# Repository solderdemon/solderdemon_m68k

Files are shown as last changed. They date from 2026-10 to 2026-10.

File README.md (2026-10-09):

# SolderDemon m68k

Assembled rosco r2.42 mainboard, the GAL version SolderDemon m68k r1 grew from

SolderDemon develops a line of Motorola 68k computers built from **through-hole (THT) parts**. This repository holds its mainboard: the board design, firmware, software and CPLD code. Expansion boards such as the [busboard](https://github.com/solderdemon/solderdemon_m68k-busboard) plug into its J3 expansion connector.

The mainboard is built on [rosco_m68k](https://github.com/rosco-m68k/rosco_m68k) by Ross Bamford, The Really Old-School Company Limited, and contributors. SolderDemon boards carry their own revision numbers, starting at r1; the rosco r2.x numbers are the history they grew from. The photo above is the assembled rosco r2.42 board, the GAL version that r1 grew from.

## The board: r1

r1 is the next release and is not made yet. KiCad renders of it, top and bottom:

<p>
  SolderDemon m68k r1, top side, KiCad render
  SolderDemon m68k r1, bottom side with the SolderDemon identity, KiCad render
</p>

| | |
| --- | --- |
| CPU | MC68010, 10 MHz |
| Memory | 1 MB Flash ROM (2 × SST39SF040), 1 MB SRAM (2 × AS6C4008) |
| Glue logic | 2 × ATF1502AS CPLD in PLCC-44 sockets, programmed in circuit over JTAG (J9) |
| I/O | XR68C681 DUART: two UARTs (J1, J2), SD card over SPI (J4) |
| Expansion | 64-pin J3 connector |
| PCB | 165 × 100 mm, 4 layers |

What changed from rosco r2.42 is in the [design notes](design/README.md).
The [r1 first-order sheet](docs/ORDER_R1.md) links the factory ZIP and check reports for a
five-board prototype run.

## Find your way around

| What you need | Where to go |
| --- | --- |
| Board design | [design](design/README.md) |
| BOM, jumper settings, memory map, and expansion pinout | [docs](docs/README.md) |
| Firmware and ROM code | [code/firmware](code/firmware/) |
| PLD source and programming | [PLD guide](code/pld/README.md) |
| Software, libraries, and examples | [code/software](code/software/) |
| Recommended software workflow | [rosco CLI and Docker guide](docs/development.md) |
| Emulator for rosco_m68k and rosco_6502 | [SolderDemon rosco-emulator](https://github.com/solderdemon/rosco-emulator) |

## Develop software

For new programs, use [rosco CLI](https://github.com/solderdemon/rosco-cli) with its Docker build workflow. It creates the current starter project, builds through Docker, and can upload and monitor over UART. Follow the [quick start](docs/development.md).

## At the bench

- Start with the [hardware build guide](design/README.md) and [bill of materials](docs/BOM.md).
- Check [power and jumper settings](docs/JUMPERS.md) before applying power, particularly JP1/JP2 for FTDI power and JP3 for Flash writes.
- Use the [J3 expansion header pinout](docs/EXPANSION.md) for peripherals. J3 is the header; JP3 is a different, two-pin jumper.
- For code builds, see the [firmware and software overview](code/README.md). The [older SD card guide](docs/legacy-sd-card.md) covers earlier board revisions and is kept for code users.

<details>
<summary>Photos from the project's early prototypes</summary>

These images show early project prototypes, not the assembled r2.42 board shown above.

Early populated prototype
Early prototype PCBs

</details>

## Licences and attribution

Hardware design: [CERN Open Hardware Licence v1.2](LICENCE.hardware.txt). Software: [MIT](LICENSE) with [third-party notices](licenses/README.md). Documentation: [Creative Commons Attribution 4.0](licenses/LICENSE.docs). Original rosco_m68k design and documentation: Ross Bamford, The Really Old-School Company Limited, and contributors. See [upstream](https://github.com/rosco-m68k/rosco_m68k) for complete history and documentation.

**SolderDemon modification notice (2026-09-30):** SolderDemon m68k adapts the original rosco_m68k project, including a reworked through-hole mainboard (CPLDs instead of GALs, r1 layout and identity), the CPLD logic, and the build documentation. The original authorship and licence notices remain with the source files.

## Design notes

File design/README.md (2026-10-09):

# SolderDemon m68k through-hole mainboard design

Assembled r2.42 mainboard, the GAL version this board grew from

This directory contains the SolderDemon m68k through-hole mainboard design, derived from the original [rosco_m68k](https://github.com/rosco-m68k/rosco_m68k) board. Open the [KiCad project](kicad/solderdemon_m68k.kicad_pro) to inspect the board. The schematics are split into CPU, memory, CPLDs, DUART, reset, and expansion sheets. A [schematic PDF](kicad/solderdemon_m68k.pdf) is included for quick reading.

## Build references

1. Review the [bill of materials](../docs/BOM.md). Its source is the [KiCad CSV export](kicad/solderdemon_m68k.csv); confirm each footprint and package before ordering.
2. Read [jumper and power notes](../docs/JUMPERS.md) before applying power or connecting an SD card.
3. Use the [J3 expansion pinout](../docs/EXPANSION.md) when making an expansion board. **J3** is the expansion connector; **JP3** is the Flash write-enable jumper.
4. For an r1 PCB order, follow the [first-order sheet](../docs/ORDER_R1.md) and use the [r1 factory ZIP](CAMOutputs/solderdemon_m68k-r1-factory.zip). Its Gerbers and drills are generated from the current board; the [DRC report](CAMOutputs/solderdemon_m68k-r1-drc.rpt), [ERC report](CAMOutputs/solderdemon_m68k-r1-erc.rpt), [schematic PDF](CAMOutputs/solderdemon_m68k-r1-schematic.pdf), and [BOM](CAMOutputs/solderdemon_m68k-r1-bom.csv) are alongside it. Regenerate all of them after any design change.

## Contents

- **kicad/**: editable schematic sheets, PCB, project, local symbols and footprints, CSV BOM export, and schematic PDF.
- **tools/**: the scripts that turn r2.13 into r1 (below).
- **CAMOutputs/**: current r1 Gerber layers, drill files, first-order ZIP, BOM, PDF, and reports.
- **docs/**: [BOM, jumper notes, and expansion pinout](../docs/README.md).

## r1: SolderDemon numbering, the DUART in the CPLD column

From here on the board carries its own revision numbers, starting at **r1**; the r2.x numbers
below are the rosco_m68k history it grew from.

r1 puts the three PLCC-44 sockets in one column: IC3 (glue), IC2 (decoder) and the DUART IC4
under them. IC4 used to sit 8 mm to the right, and moving it left would have put its pins on the
RAM U4, so the board is 5 mm longer instead (165 × 100 mm). `tools/r1_layout.py` stretches the
r2.42 board along a cut between the CPLDs and the CPU/RAM: everything right of the cut moves 5 mm
right, tracks crossing the cut get a horizontal bridge, so no clearance shrinks. IC4 then moves
into the column, its decoupling cap C22 into the space it left, and the DUART is routed again.
The upstream badges (WEEE bin, OSHW block, rosco_m68k logos, GitHub URL) are gone from the
silkscreen (`tools/strip_silk.py`). The CPU decoupling C20/C12/C29/C31 stands in an even column in the gap the stretch
opened, and the back carries the SolderDemon identity as on the busboard: the logo, the name and
"M68K Computer r1" (`tools/r1_identity.py`). All silkscreen text is in KiCad's own font; the
Futura that r2.x asked for is not installed and made KiCad stop at a message box.

## First r1 prototype order

The r1 board is **165 × 100 mm, four copper layers**. Generate the order package with
KiCad 10 Python from the repository root:

```sh
"/c/Program Files/KiCad/10.0/bin/python.exe" design/tools/export_r1.py
```

The script gates on zero ERC/DRC errors and zero unconnected pads, then replaces the files in
`design/CAMOutputs/`. Send only `solderdemon_m68k-r1-factory.zip` to the PCB manufacturer;
it contains the four copper layers, both masks, both silkscreens, outline, and PTH/NPTH drills.
For the first run, order **five bare PCBs** and populate one after checking the physical fit of
the three PLCC-44 sockets, JTAG header orientation, and other chosen components. The CSV BOM
is a design list; choose and verify supplier parts before buying components.

The existing route was improved for `D6` and `A18` with `design/tools/optimize_r1_routes.py`.
That script accepts a shorter route only when it uses no more vias and KiCad DRC remains clean.
Run the export script again if any routing or silkscreen changes are made.

## Revision 2.42: finished CPLD mainboard

r2.42 removes the J6 address/EXPSEL breakout and the J7 SPI CS2 breakout. Their unused copper
branches are pruned and the affected A1/FC2 routes are reconnected. Sixteen narrow VCC bridge
segments are widened from 0.2 to 0.3 mm. The board and all schematic title blocks carry revision
2.42; the crowded UART pin text and obsolete header labels are removed from the silkscreen.

## Revision 2.14: two ATF1502AS instead of four GALs

r2.14 replaces the four ATF22V10C GALs (IC2, IC3, IC5, IC6) with two ATF1502AS-10JU44 CPLDs in
through-hole PLCC-44 sockets, programmed in circuit through the JTAG header **J9**. The logic and
its check are described in [code/pld/cpld](../code/pld/cpld/README.md). Both sockets sit one above
the other where the three glue GALs stood; the old IC2 gap between the CPU and the ROMs is 24.4 mm
and a socket is 24.6 mm. J8, R31, R32 and R16 moved left to make room; the old GAL
decoupling C23-C25 and the DUART's C27/C28 now stand in one column under J9, and C33 is new.

r2.13 was drawn by hand, so r2.42 is an *edit* of it made by scripts, always starting
again from the r2.13 board in git. To rebuild it (KiCad 10, Docker for the fitter):

```sh
K="/c/Program Files/KiCad/10.0/bin"
./code/pld/cpld/build.sh                  # 1. *.pld -> bin/*.jed, pins checked against the source
python design/tools/verify_cpld.py        # 2. CPLDs against the r2.13 GAL fuse maps
python design/tools/cpld_sch.py           # 3. CPLDs sheet of the schematic, from the PIN lines
"$K/python.exe" design/tools/cpld_board.py   # 4. GALs out, sockets/J9/caps in, nets from the schematic
"$K/python.exe" design/tools/cpld_route.py   # 5. routing with KiCadRoutingTools, planes, cleanup
"$K/python.exe" design/tools/remove_access_headers.py # 6. remove J6/J7 and set revision 2.42
"$K/python.exe" design/tools/cpld_route.py --finish     # 7. prune obsolete header branches
"$K/python.exe" design/tools/repair_dangling.py        # 8. remove the remaining old stubs
"$K/python.exe" design/tools/cpld_route.py             # 9. reconnect affected nets
"$K/python.exe" design/tools/repair_dangling.py        # 10. repeat for residual stubs
"$K/python.exe" design/tools/cpld_route.py             # 11. finish the reconnection
"$K/python.exe" design/tools/polish_board.py           # 12. wider VCC bridges, clean silkscreen
"$K/python.exe" design/tools/brand_project.py          # 13. apply SolderDemon m68k project branding
python design/tools/strip_silk.py                      # 14. upstream badges off the silkscreen
"$K/python.exe" design/tools/r1_layout.py              # 15. r1: longer board, DUART into the column
"$K/python.exe" design/tools/cpld_route.py             # 16. route the DUART again
"$K/python.exe" design/tools/trim_stubs.py             # 17. cut router overshoots back to their junctions
python design/tools/make_logo.py 17                    # 18. SolderDemon logo footprint, as on the busboard
"$K/python.exe" design/tools/r1_identity.py            # 19. CPU decoupling column, SolderDemon identity on the back
"$K/python.exe" design/tools/cpld_route.py             # 20. route what the column tore up
"$K/python.exe" design/tools/trim_stubs.py             # 21. and trim again
"$K/kicad-cli.exe" pcb drc --schematic-parity design/kicad/solderdemon_m68k.kicad_pcb
```

Steps 5, 9 and 11 use [KiCadRoutingTools](https://github.com/drandyhaas/KiCadRoutingTools) from the
workspace's `tools/KiCadRoutingTools` (set `KRT` to use another clone); its logs go to
`design/kicad/routing/`. `design/tools/check_board.py` prints the DRC of any board with its
zones refilled.

The hardware design is licensed under [CERN OHL v1.2](../LICENCE.hardware.txt). The documentation is attributed in the [repository README](../README.md).

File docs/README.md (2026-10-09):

# SolderDemon m68k documentation

## Through-hole board

- [r1 first-order sheet](ORDER_R1.md): factory ZIP, board parameters and pre-order checks.
- [Parts and quantities](BOM.md): bill of materials from the KiCad CSV export.
- [Jumpers, power, and SD card](JUMPERS.md): JP1 through JP4 and the 5 V SD interface.
- [J3 expansion pinout](EXPANSION.md): 64-pin header signals and electrical notes.
- [Memory map](MEMORY-MAP.md): RAM, expansion, ROM, I/O, and firmware-reserved RAM.
- [Hardware design guide](../design/README.md): KiCad source, schematic PDF, and CAM files.

## Code

- [Recommended rosco CLI and Docker workflow](development.md)
- [Emulator workflow](development.md#emulate-the-board) for the SolderDemon m68k and rosco_6502 targets

- [Firmware and software overview](../code/README.md)
- [Firmware interface reference](../code/firmware/rosco_m68k_firmware/InterfaceReference.md)
- [Toolchain setup](../code/Toolchain.md)
- [PLD source and programming](../code/pld/README.md)
- [Legacy SD card guide](legacy-sd-card.md), written for older board revisions

These board notes are adapted from the original project documents. See the [repository README](../README.md) for attribution and licences.

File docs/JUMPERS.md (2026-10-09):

# Jumpers, power, and SD card

These notes are adapted from the original *Classic v2 Additional Information* sheet for the through-hole mainboard. Confirm jumper positions against the [r1 schematic](../design/kicad/solderdemon_m68k.pdf) and board silkscreen before applying power.

| Jumper | Closed | Normal use |
| --- | --- | --- |
| JP1 / JP2 | Allows power from the corresponding FTDI serial module | Leave both open when using the board's external power input. Close **only one** when deliberately powering through an FTDI module. |
| JP3 | Enables hardware writing to the Flash ROMs | Leave open unless running a Flash update. |
| JP4 | Changes expansion RAM behaviour for the original rosco_m68k memory expansion board | Leave open for other configurations. |

## Power through FTDI

Never close JP1 and JP2 together. Do not connect external power while either FTDI power jumper is closed. The original R2 notice states the mainboard alone requires **at least 500 mA**; check that the host and FTDI module can supply the complete build.

## SD card header

The SPI SD card header uses **5 V** signals. Use an Arduino-compatible SD card adapter with built-in **5 V to 3.3 V level conversion**. Do not connect a bare 3.3 V SD card directly.

## Expansion power

The J3 expansion connector exposes 5 V and ground. The original [J3 pinout](EXPANSION.md) recommends drawing no more than **500 mA** from its 5 V pin, with **1 A** stated as an absolute maximum. Account for the complete board's power supply and use a shared ground if powering a peripheral separately.

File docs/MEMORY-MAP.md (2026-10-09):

# Memory map

This is the physical 24-bit address map of the through-hole mainboard after startup. The current [IC2 CPLD source](../code/pld/cpld/ic2_decoder.pld) defines the r1 board-level regions; the [firmware linker script](../code/firmware/rosco_m68k_firmware/rosco_m68k_firmware_1M.ld) and [program linker script](../code/software/libs/src/start_serial/link_scripts/hugerom_rosco_m68k_program.ld) use the same boundaries.

| Address range | Size | Use |
| --- | ---: | --- |
| `0x000000`–`0x0FFFFF` | 1 MiB | Onboard RAM |
| `0x100000`–`0xDFFFFF` | 13 MiB | Expansion address space; memory or devices depend on the attached hardware |
| `0xE00000`–`0xEFFFFF` | 1 MiB | Onboard ROM / Flash |
| `0xF00000`–`0xFFFFFF` | 1 MiB | I/O address space |

At reset, the address decoder temporarily selects ROM at low addresses so the CPU can fetch its initial vectors. After the startup cycles, RAM occupies `0x000000`–`0x0FFFFF`. The ROM image and firmware revision word are linked at `0xE00000` and `0xE00400` respectively. The DUART is addressed at odd byte addresses starting at `0xF00001`; see the [firmware register definitions](../code/firmware/rosco_m68k_firmware/include/machine.h). The I/O region is a decode window, not a promise that every address in it has a device.

## Low RAM used by firmware

The firmware reserves the first `0x2000` bytes for vectors and system data. The ranges below come from the [firmware interface reference](../code/firmware/rosco_m68k_firmware/InterfaceReference.md#2-system-data-area-memory-map).

| Address range | Use |
| --- | --- |
| `0x000000`–`0x0003FF` | Exception vectors |
| `0x000400`–`0x00041F` | System Data Block (SDB), including RAM size and UART base |
| `0x000420`–`0x0004FF` | Firmware function pointer table |
| `0x000500`–`0x00117F` | Video I/O data area |
| `0x001180`–`0x0017FF` | Firmware internal reserved area |
| `0x001800`–`0x001FFF` | Firmware BSS |

The standard program linker script begins its run area at `0x002000`. It also uses `0x040000` as a load address, so use the linker script for a program's actual layout instead of treating all higher RAM as free. For individual SDB fields and firmware calls, use the [full interface reference](../code/firmware/rosco_m68k_firmware/InterfaceReference.md).

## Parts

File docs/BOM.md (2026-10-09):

# SolderDemon m68k bill of materials

This table is based on the current r1 [KiCad CSV export](../design/kicad/solderdemon_m68k.csv). It has **30 part lines and 82 component placements**, excluding four mounting holes. The [order-package BOM](../design/CAMOutputs/solderdemon_m68k-r1-bom.csv) is generated from the same schematic. These are design BOMs, not verified purchasing lists; check the schematic, PCB footprints, and chosen supplier parts before buying components.

| Qty | References | Value / part | KiCad footprint |
| ---: | --- | --- | --- |
| 1 | S1 | 10-XX | B3F-10XX |
| 2 | R19,R11 | 10K | 0207_10 |
| 2 | C1,C2 | 7pF | C2.5_or_3.5-3 |
| 23 | C7,C8,C9,C20,C23,C24,C22,C26,C13,C27,C28,C30,C31,C6,C25,C29,C12,C10,C5,C4,C3,C32,C33 | 100nF | C2.5-3 |
| 7 | C16,C17,C18,C19,C14,C15,C11 | 100uF | E2,5-5 |
| 1 | C21 | 470uF | E3,5-10 |
| 1 | IC4 | XR68C681CJTR-F | PLCC-44_THT-Socket |
| 2 | IC3,IC2 | ATF1502AS-10JU44 | PLCC-44_THT-Socket |
| 4 | JP1,JP2,JP3,JP4 | Jumper | 1X02 |
| 2 | LED3,LED1 | GREEN | LED5MM |
| 2 | LED4,LED2 | RED | LED5MM |
| 1 | Q1 | 3.6864MHz | Crystal_HC49-4H_Vertical |
| 1 | Q2 | 5H8ET-10.000 | Oscillator_DIP-8 |
| 2 | U4,U3 | AS6C4008-55PCN | DIP-32_W15.24mm_LongPads |
| 2 | U2,U1 | SST39SF040 | DIP-32_W15.24mm_LongPads |
| 1 | J3 | Conn_02x32_Odd_Even | PinHeader_2x32_P2.54mm_Vertical |
| 12 | R8,R7,R9,R10,R32,R31,R12,R15,R17,R18,R3,R16 | 4K7 | 0207_10 |
| 1 | J4 | Conn_01x06 | 1X06 |
| 1 | J2 | UART_B | 1X06 |
| 1 | J1 | UART_A | 1X06 |
| 1 | J5 | PWR | 1X02 |
| 1 | IC15 | 555N | DIP-8_W7.62mm_LongPads |
| 1 | R27 | 2K2 | 0207_10 |
| 1 | R28 | 270R | 0207_10 |
| 4 | R13,R14,R1,R2 | 330R | 0207_10 |
| 1 | R21 | 1K2 | 0207_10 |
| 1 | IC7 | 74LS148 | DIP-16_W7.62mm_LongPads |
| 1 | J8 | Conn_01x02_Male | PinHeader_1x02_P2.54mm_Vertical |
| 1 | IC1 | MC68010P10 | DIL64 |
| 1 | J9 | JTAG (2x5 header) | PinHeader_2x05_P2.54mm_Vertical |

## Items outside the component count

- The CSV also contains **four M3 mounting holes** and **six logo or compliance artwork objects**. They are PCB features, not parts to buy.
- The bare PCB and any required programming of the ATF1502AS CPLDs (in circuit, over JTAG header J9) and Flash ROMs are not included as BOM lines. See the [PLD programming guide](../code/pld/README.md) for IC2 and IC3. Boards up to r2.13 use four ATF22V10C GALs (IC2, IC3, IC5, IC6) instead.
- The original R2 packing list separately mentioned sockets for IC1 (DIL64, 1), IC4 (PLCC44, 1), IC7 (DIL16, 1), IC15 (DIL08, 1), and U1/U2/U3/U4 (DIL32, 4). From r2.14 IC2 and IC3 also sit in PLCC-44 through-hole sockets (2 more PLCC44 sockets). Treat these as assembly choices and verify fit against the PCB.
- The older packing list differs from this KiCad CSV for some headers (including J8). This table follows the CSV; inspect the current PCB before ordering those headers.

The source CSV has no supplier or manufacturer part numbers. Package names in this table are KiCad footprint identifiers, not vendor order codes.

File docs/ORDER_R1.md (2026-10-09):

# SolderDemon m68k r1 — first PCB order

Order **five bare boards**; assemble and test one before populating the rest.

| Order field | r1 design value |
| --- | --- |
| Fabrication upload | [`solderdemon_m68k-r1-factory.zip`](../design/CAMOutputs/solderdemon_m68k-r1-factory.zip) |
| Finished outline | 165 × 100 mm |
| Layers | 4: Top, Route2, Route15, Bottom |
| Material and thickness | FR-4, 1.6 mm |
| Copper in KiCad stackup | 0.035 mm on each layer (1 oz nominal) |
| Solder mask / silkscreen files | Both sides included |
| Drill files | Separate PTH and NPTH Excellon files; NPTH contains no holes |

The KiCad stackup leaves the copper surface finish as `None`; choose the finish in the
manufacturer's order form. Solder-mask colour and legend colour are also order-form choices;
the project renders show green mask with white legend. Check the rendered preview for all four
copper layers, outline, masks, both legends and plated holes before submitting the order.

The [ERC report](../design/CAMOutputs/solderdemon_m68k-r1-erc.rpt) has zero errors. The
[DRC report](../design/CAMOutputs/solderdemon_m68k-r1-drc.rpt) has zero errors and zero
unconnected pads; its warnings are library footprint and schematic field differences. The
[drill report](../design/CAMOutputs/solderdemon_m68k-r1-drill-report.txt) lists 1,122 plated
holes. The factory ZIP was regenerated from the current r1 board after route optimization.

For the first assembly, use the [current BOM](../design/CAMOutputs/solderdemon_m68k-r1-bom.csv)
and [schematic PDF](../design/CAMOutputs/solderdemon_m68k-r1-schematic.pdf). Verify the actual
PLCC-44 socket bodies and key orientation for IC2, IC3 and IC4, and the J9 JTAG connector
orientation before soldering. The BOM is a design list, not a supplier-verified shopping list.

If the PCB changes, regenerate all files with KiCad 10 Python:

```sh
"/c/Program Files/KiCad/10.0/bin/python.exe" design/tools/export_r1.py
```

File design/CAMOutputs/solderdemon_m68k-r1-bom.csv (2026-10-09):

Refs | Value | Footprint | Qty | DNP
C1,C2 | 7pF | rosco_m68k:C2.5_or_3.5-3 | 2
C3-C10,C12,C13,C20,C22-C33 | 100nF | rosco_m68k:C2.5-3 | 23
C11,C14-C19 | 100uF | rosco_m68k:E2,5-5 | 7
C21 | 470uF | rosco_m68k:E3,5-10 | 1
H1-H4 | MountingHole | MountingHole:MountingHole_3.2mm_M3_Pad | 4
IC1 | MC68010P10 | rosco_m68k:DIL64 | 1
IC2,IC3 | ATF1502AS-10JU44 | Package_LCC:PLCC-44_THT-Socket | 2
IC4 | XR68C681CJTR-F | Package_LCC:PLCC-44_THT-Socket | 1
IC7 | 74LS148 | Package_DIP:DIP-16_W7.62mm_LongPads | 1
IC15 | 555N | Package_DIP:DIP-8_W7.62mm_LongPads | 1
J1 | UART_A | rosco_m68k:1X06 | 1
J2 | UART_B | rosco_m68k:1X06 | 1
J3 | Conn_02x32_Odd_Even | Connector_PinHeader_2.54mm:PinHeader_2x32_P2.54mm_Vertical | 1
J4 | Conn_01x06 | rosco_m68k:1X06 | 1
J5 | PWR | rosco_m68k:1X02 | 1
J8 | Conn_01x02_Male | Connector_PinHeader_2.54mm:PinHeader_1x02_P2.54mm_Vertical | 1
J9 | JTAG | Connector_PinHeader_2.54mm:PinHeader_2x05_P2.54mm_Vertical | 1
JP1-JP4 | Jumper | rosco_m68k:1X02 | 4
LED1,LED3 | GREEN | rosco_m68k:LED5MM | 2
LED2,LED4 | RED | rosco_m68k:LED5MM | 2
Q1 | 3.6864MHz | Crystal:Crystal_HC49-4H_Vertical | 1
Q2 | 5H8ET-10.000 | Oscillator:Oscillator_DIP-8 | 1
R1,R2,R13,R14 | 330R | rosco_m68k:0207_10 | 4
R3,R7-R10,R12,R15-R18,R31,R32 | 4K7 | rosco_m68k:0207_10 | 12
R11,R19 | 10K | rosco_m68k:0207_10 | 2
R21 | 1K2 | rosco_m68k:0207_10 | 1
R27 | 2K2 | rosco_m68k:0207_10 | 1
R28 | 270R | rosco_m68k:0207_10 | 1
S1 | 10-XX | rosco_m68k:B3F-10XX | 1
U1,U2 | SST39SF040 | Package_DIP:DIP-32_W15.24mm_LongPads | 2
U3,U4 | AS6C4008-55PCN | Package_DIP:DIP-32_W15.24mm_LongPads | 2

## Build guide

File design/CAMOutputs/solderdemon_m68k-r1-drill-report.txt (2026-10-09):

Drill report for solderdemon_m68k.kicad_pcb
Created on 2026-10-09T09:32:20

Copper Layer Stackup:
    =============================================================
    L1 :  Top                       front
    L2 :  Route2                    in1
    L3 :  Route15                   in2
    L4 :  Bottom                    back

Drill file 'solderdemon_m68k-PTH.drl' contains
    plated through holes:
    =============================================================
    T1  0.300mm  0.0118"  (381 holes))
    T2  0.400mm  0.0157"  (157 holes))
    T3  0.800mm  0.0315"  (290 holes))
    T4  0.813mm  0.0320"  (182 holes))
    T5  1.000mm  0.0394"  (76 holes))
    T6  1.016mm  0.0400"  (32 holes))
    T7  3.200mm  0.1260"  (4 holes))

    Total plated holes count 1122

Drill file 'solderdemon_m68k-NPTH.drl' contains
    unplated through holes:
    =============================================================

    Total unplated holes count 0

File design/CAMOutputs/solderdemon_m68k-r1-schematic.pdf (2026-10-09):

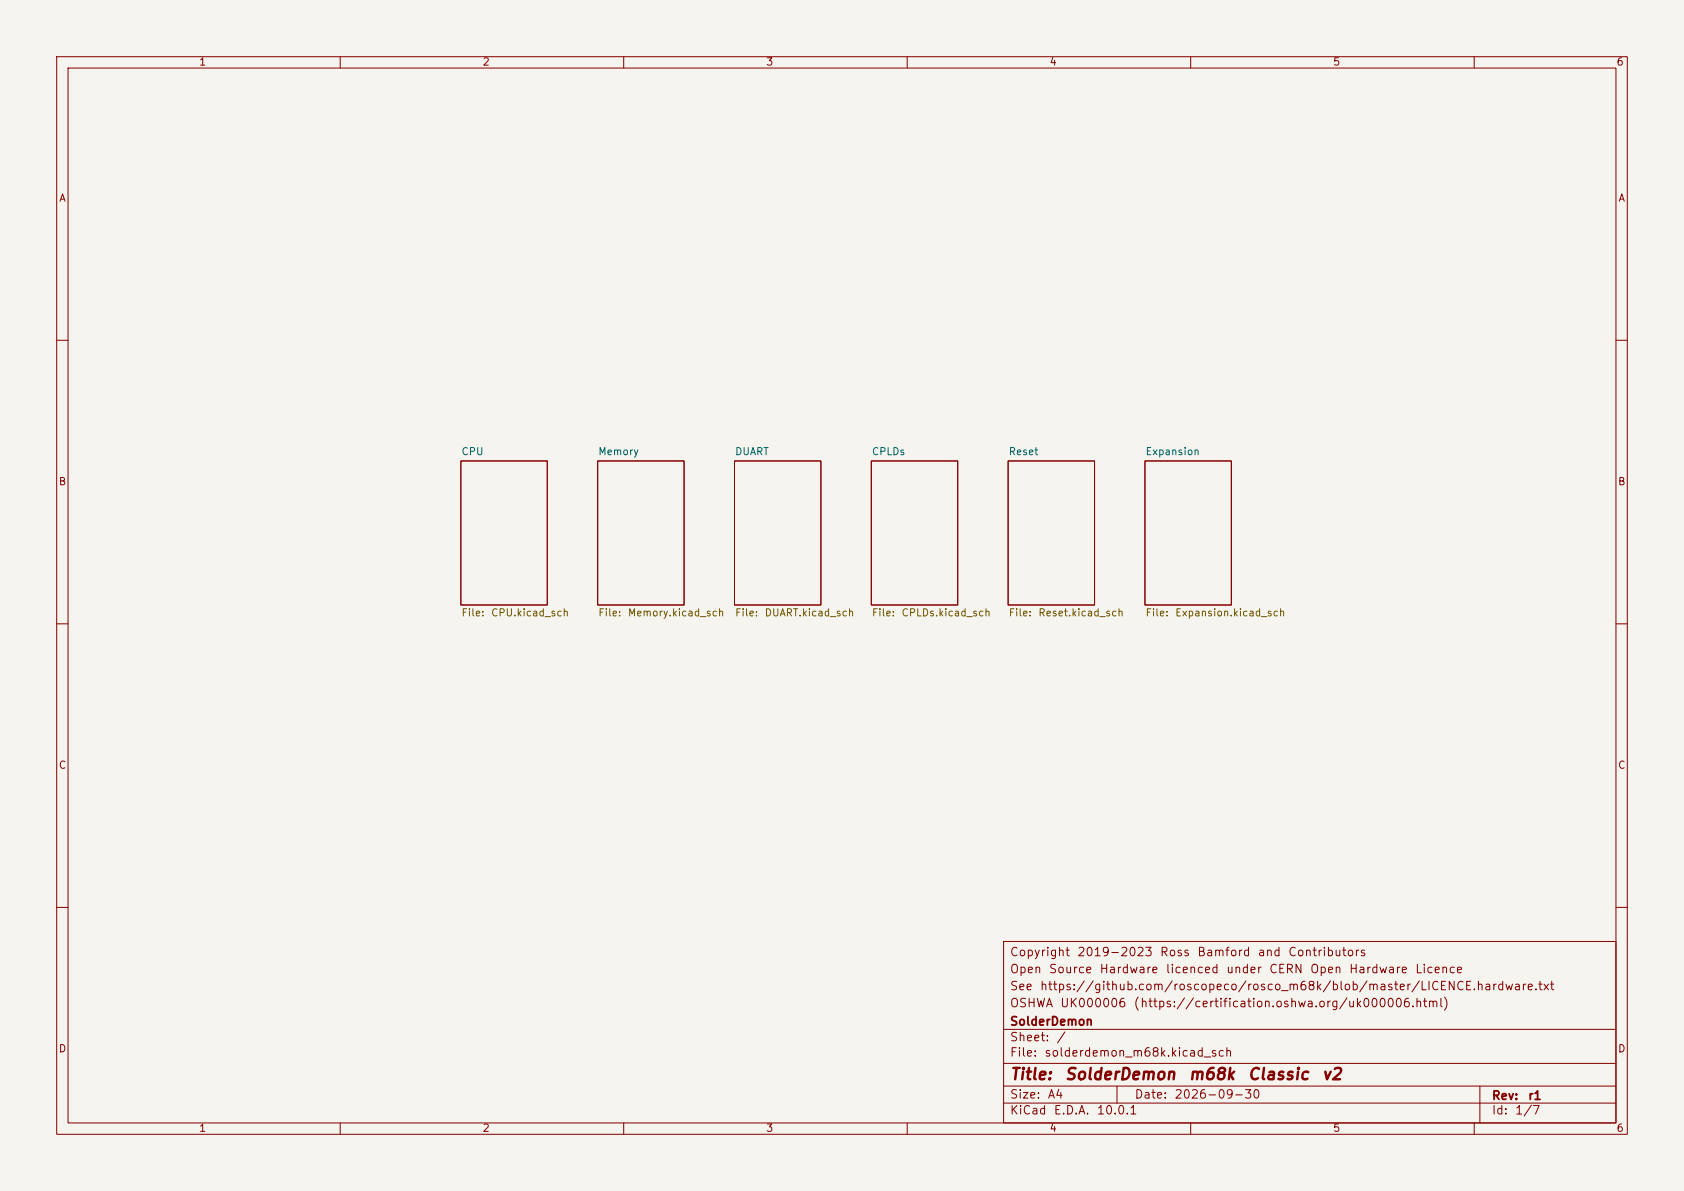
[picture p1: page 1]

Copyright 2019-2023 Ross Bamford and Contributors
Open Source Hardware licenced under CERN Open Hardware Licence
See https://github.com/roscopeco/rosco_m68k/blob/master/LICENCE.hardware.txt
OSHWA UK000006 (https://certification.oshwa.org/uk000006.html)
SolderDemon
Sheet: /
File: solderdemon_m68k.kicad_sch
Title: SolderDemon m68k Classic v2

Size: A4 | Rev: r1
KiCad E.D.A. 10.0.1 | Id: 1/7

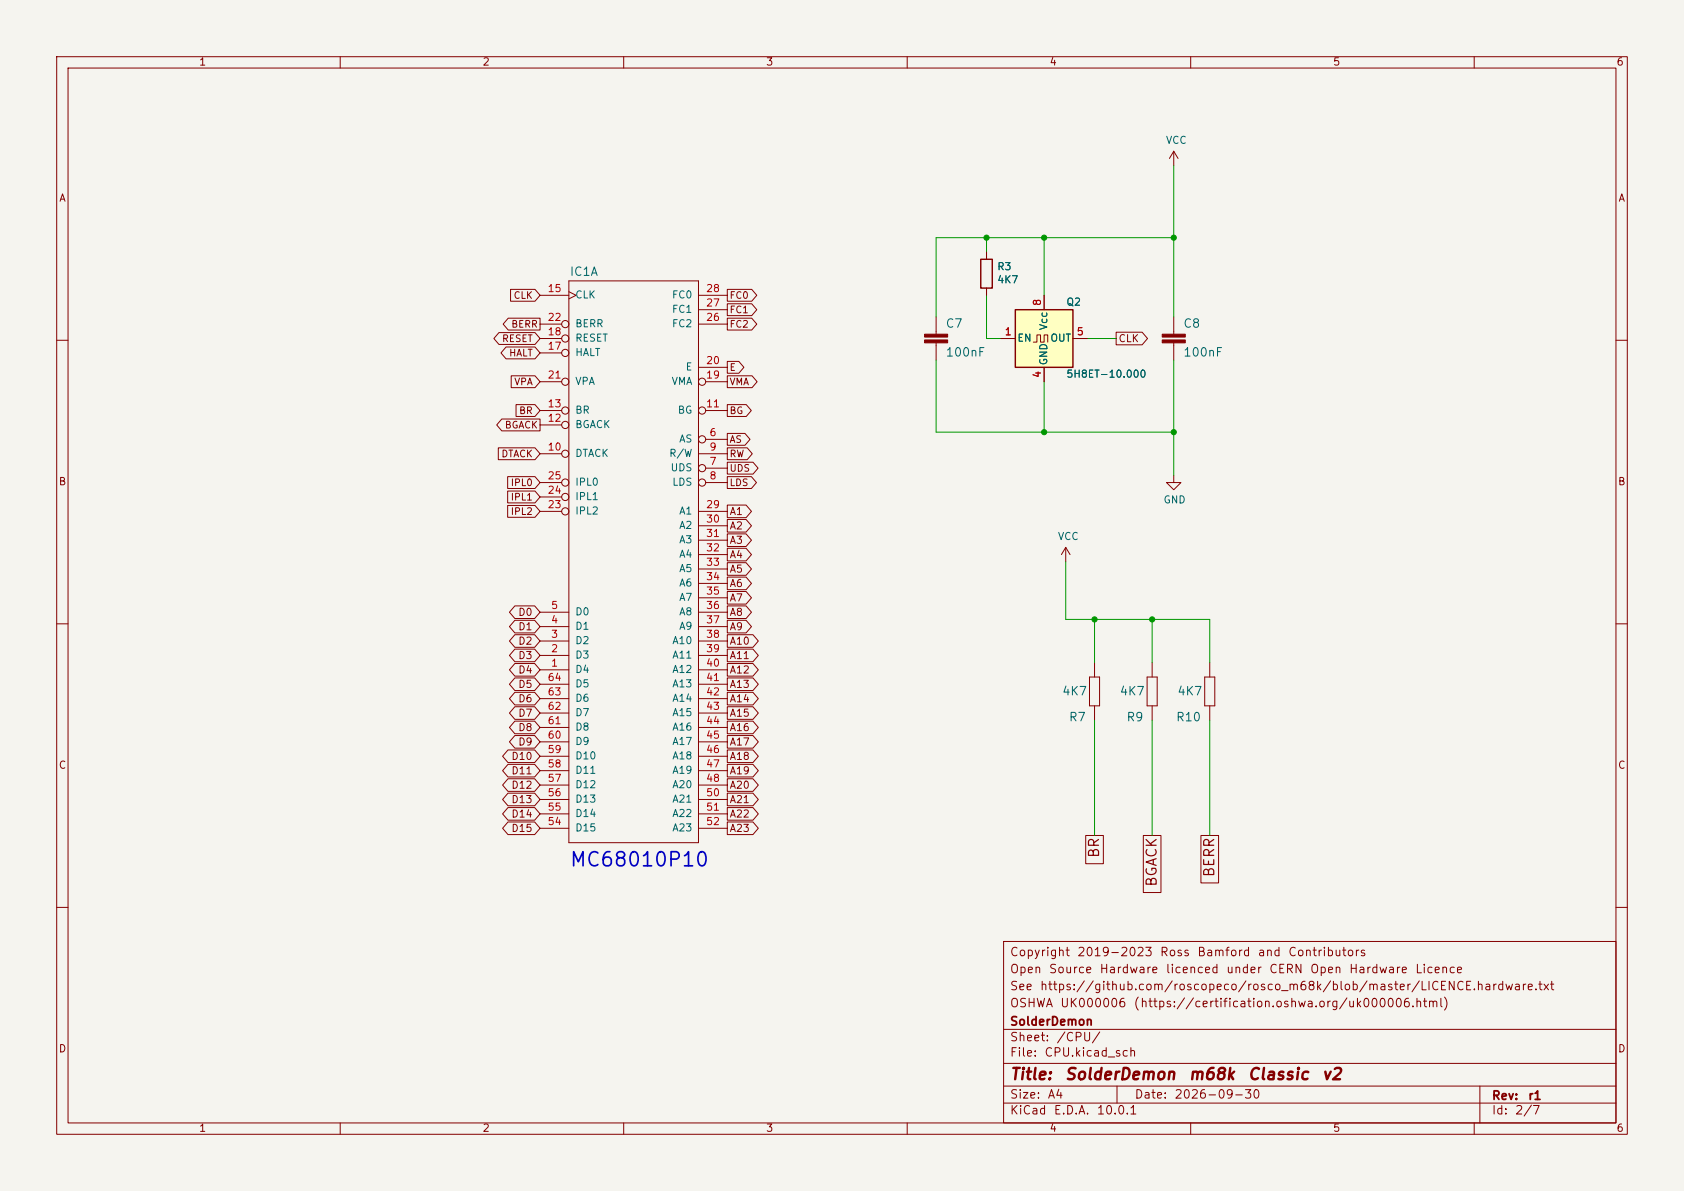
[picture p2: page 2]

Copyright 2019-2023 Ross Bamford and Contributors
Open Source Hardware licenced under CERN Open Hardware Licence
See https://github.com/roscopeco/rosco_m68k/blob/master/LICENCE.hardware.txt
OSHWA UK000006 (https://certification.oshwa.org/uk000006.html)
SolderDemon
Sheet: /CPU/
File: CPU.kicad_sch
Title: SolderDemon m68k Classic v2

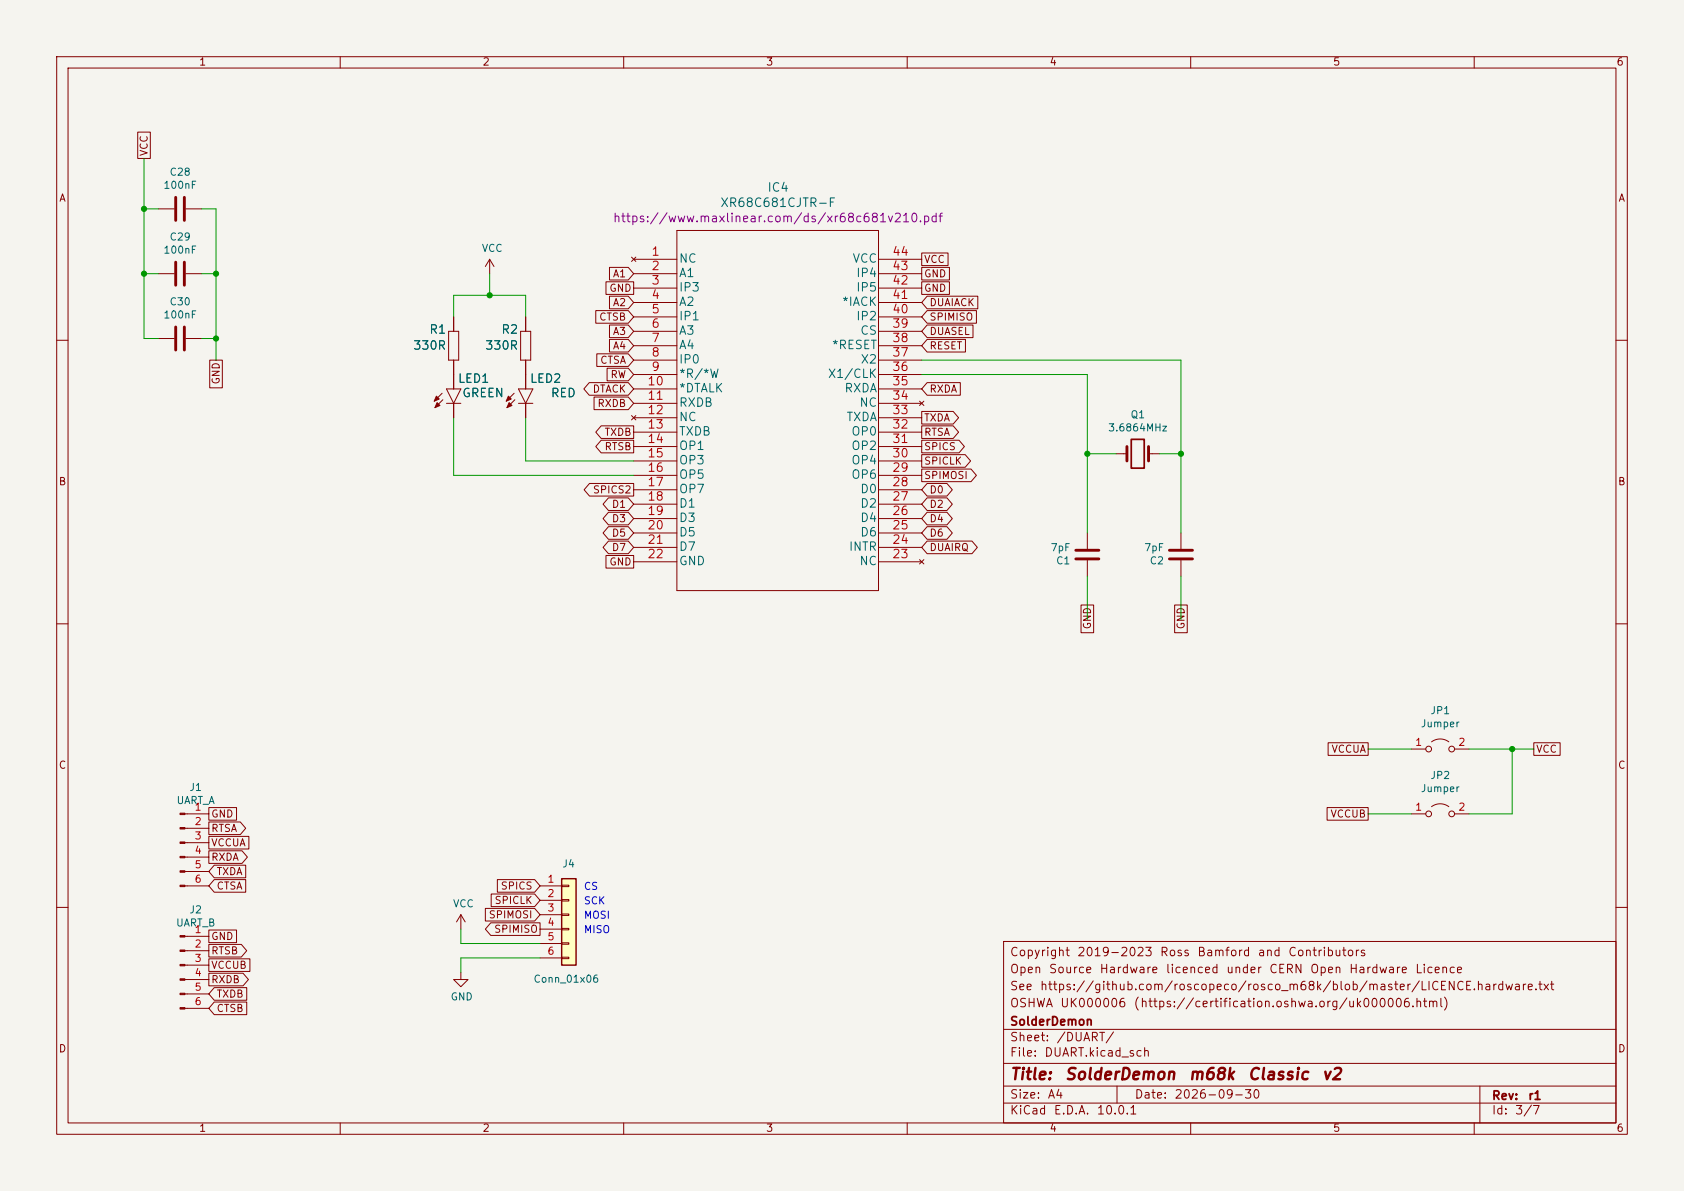
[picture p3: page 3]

Copyright 2019-2023 Ross Bamford and Contributors
Open Source Hardware licenced under CERN Open Hardware Licence
See https://github.com/roscopeco/rosco_m68k/blob/master/LICENCE.hardware.txt
OSHWA UK000006 (https://certification.oshwa.org/uk000006.html)
SolderDemon
Sheet: /DUART/
File: DUART.kicad_sch
Title: SolderDemon m68k Classic v2

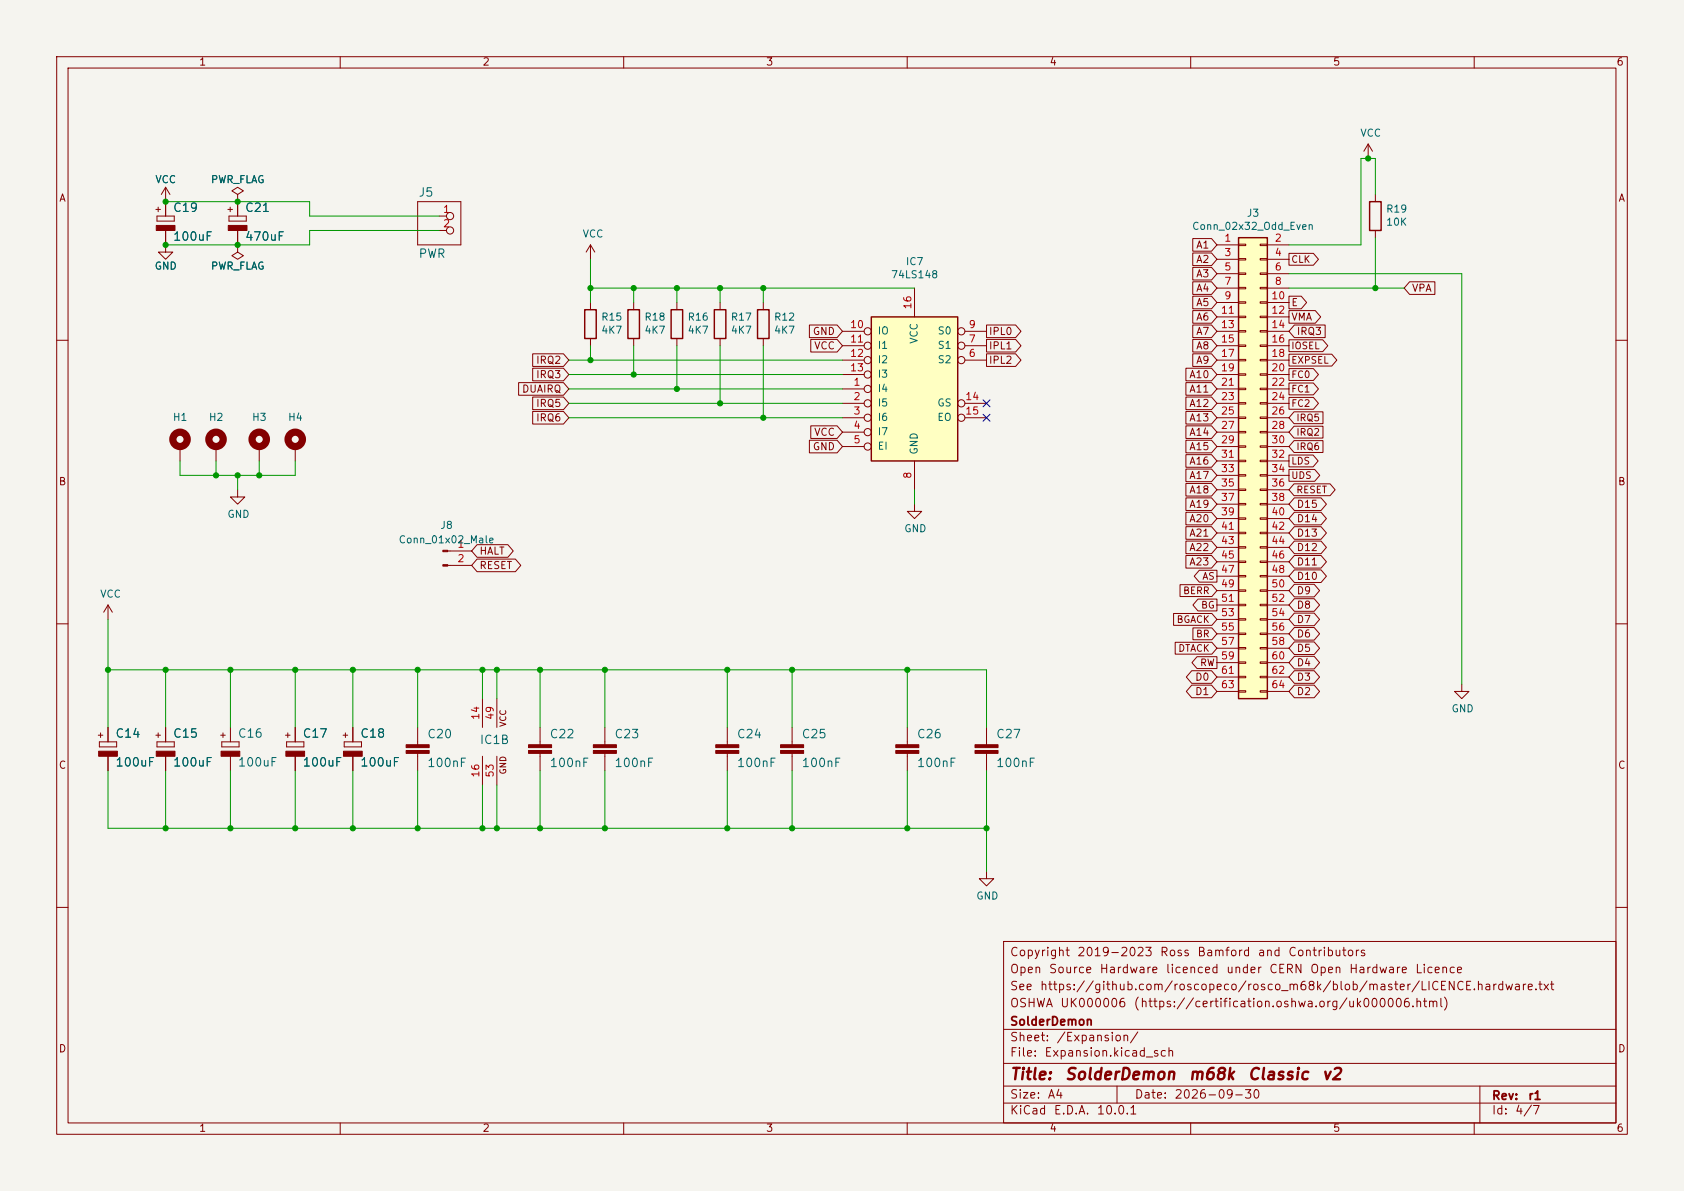
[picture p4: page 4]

Copyright 2019-2023 Ross Bamford and Contributors
Open Source Hardware licenced under CERN Open Hardware Licence
See https://github.com/roscopeco/rosco_m68k/blob/master/LICENCE.hardware.txt
OSHWA UK000006 (https://certification.oshwa.org/uk000006.html)
SolderDemon
Sheet: /Expansion/
File: Expansion.kicad_sch
Title: SolderDemon m68k Classic v2

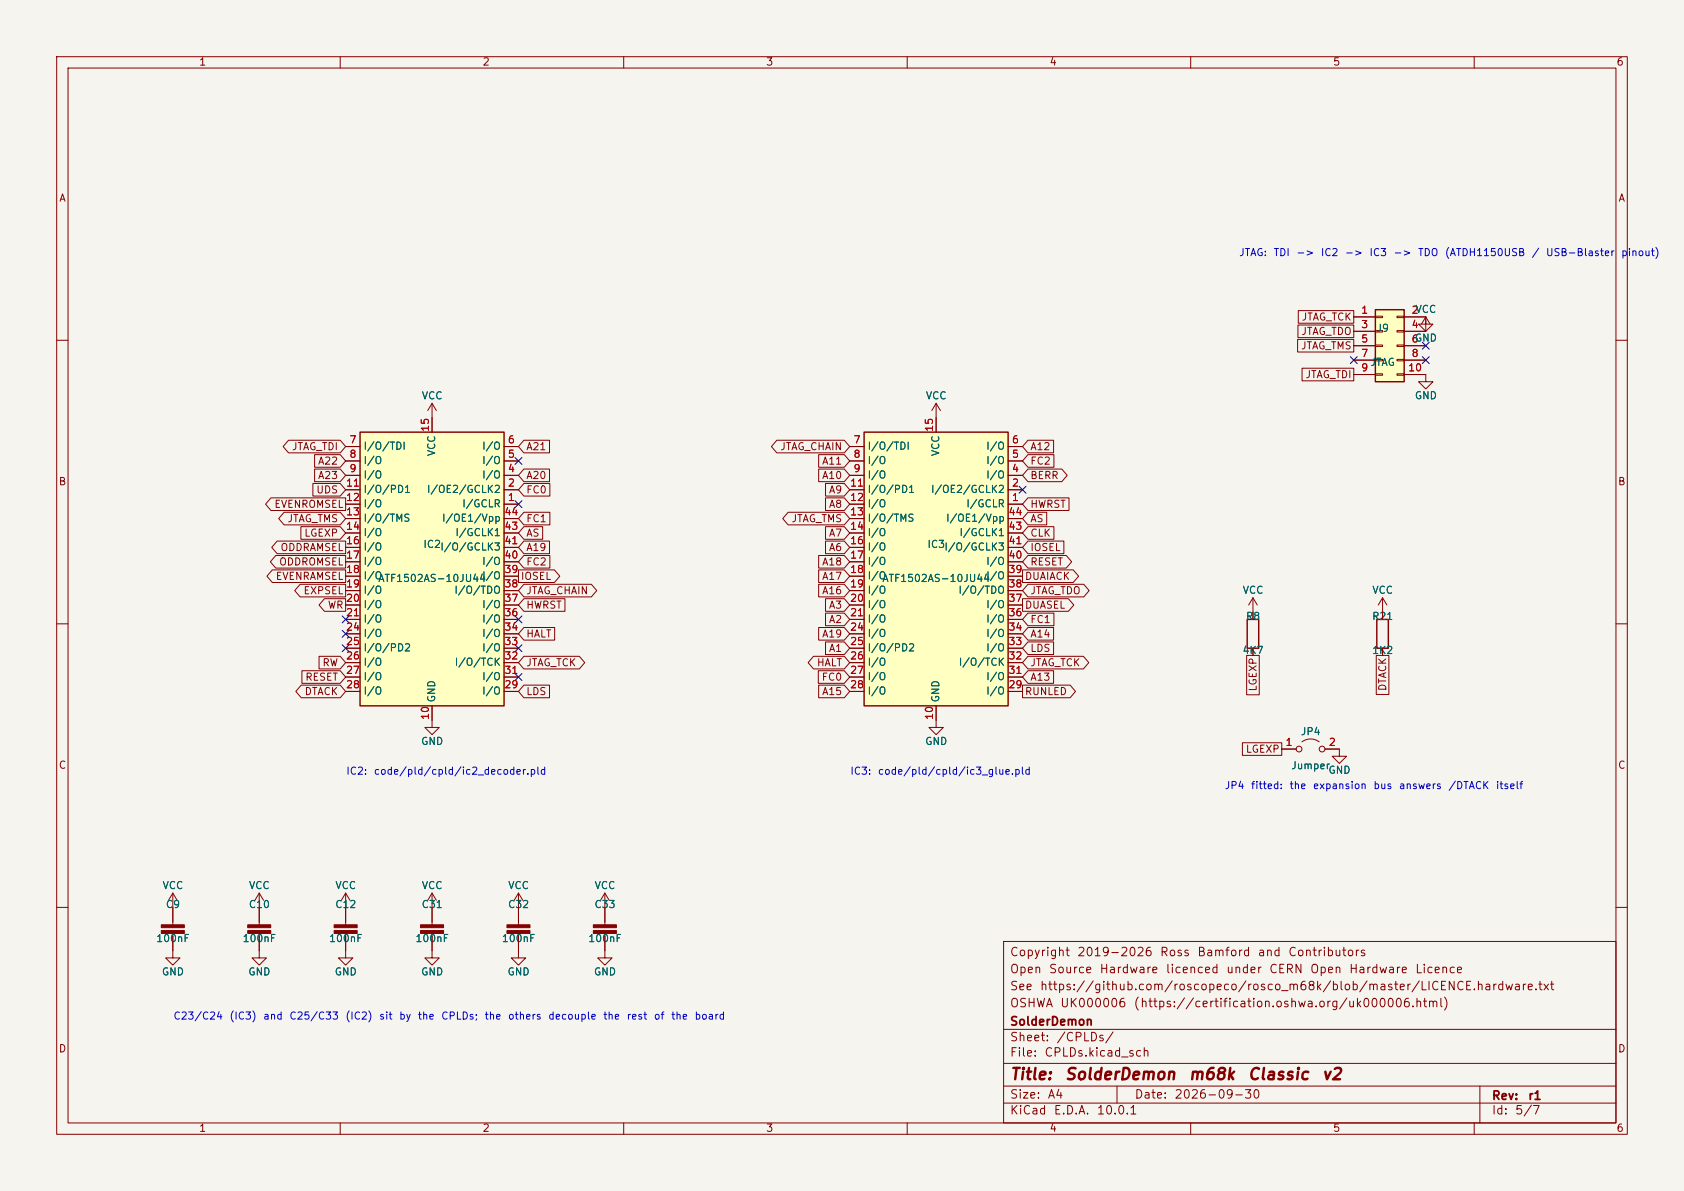
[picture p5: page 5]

JTAG: TDI -> IC2 -> IC3 -> TDO (ATDH1150USB / USB-Blaster pinout) J9

A18 C23/C24 (IC3) and C25/C33 (IC2) sit by the CPLDs; the others decouple the rest of the board

JP4 fitted: the expansion bus answers /DTACK itself

Open Source Hardware licenced under CERN Open Hardware Licence
See https://github.com/roscopeco/rosco_m68k/blob/master/LICENCE.hardware.txt
OSHWA UK000006 (https://certification.oshwa.org/uk000006.html)
SolderDemon
Sheet: /CPLDs/
File: CPLDs.kicad_sch
Title: SolderDemon m68k Classic v2

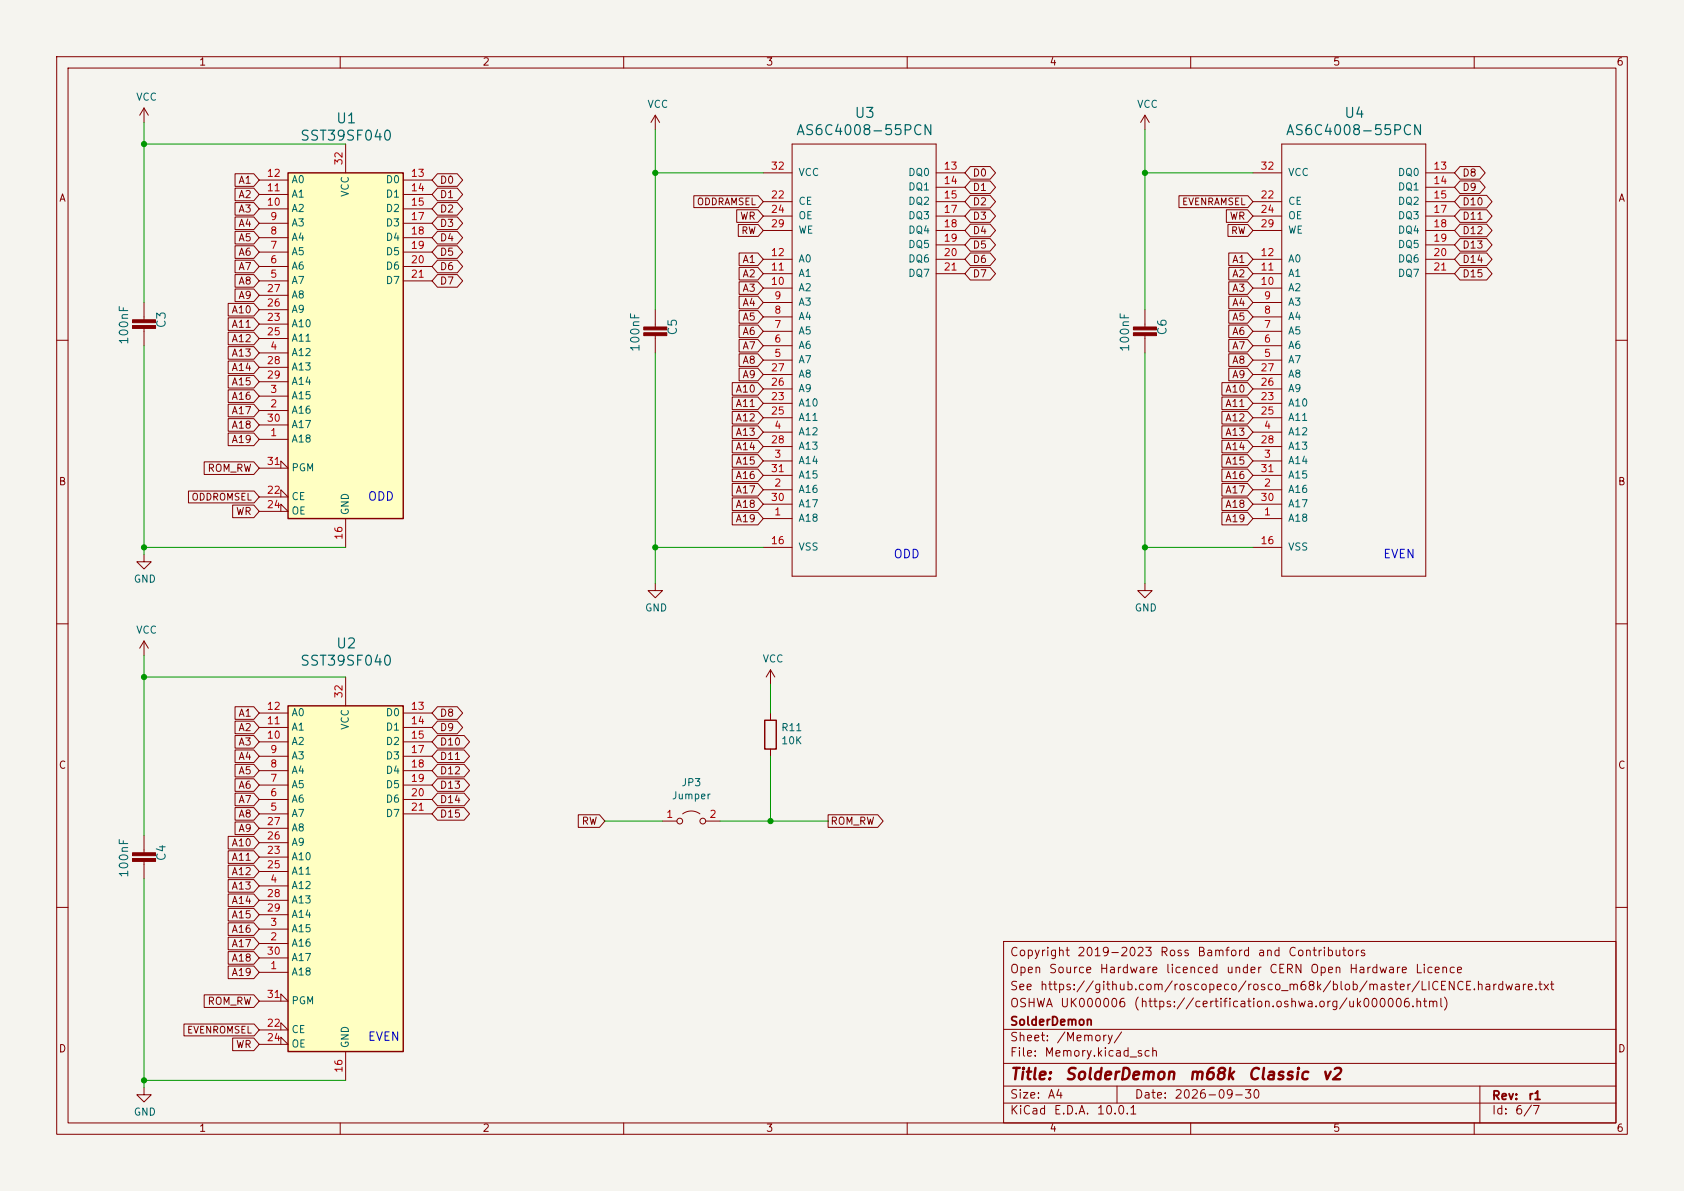
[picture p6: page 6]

Open Source Hardware licenced under CERN Open Hardware Licence
See https://github.com/roscopeco/rosco_m68k/blob/master/LICENCE.hardware.txt
OSHWA UK000006 (https://certification.oshwa.org/uk000006.html)
SolderDemon
Sheet: /Memory/
File: Memory.kicad_sch
Title: SolderDemon m68k Classic v2

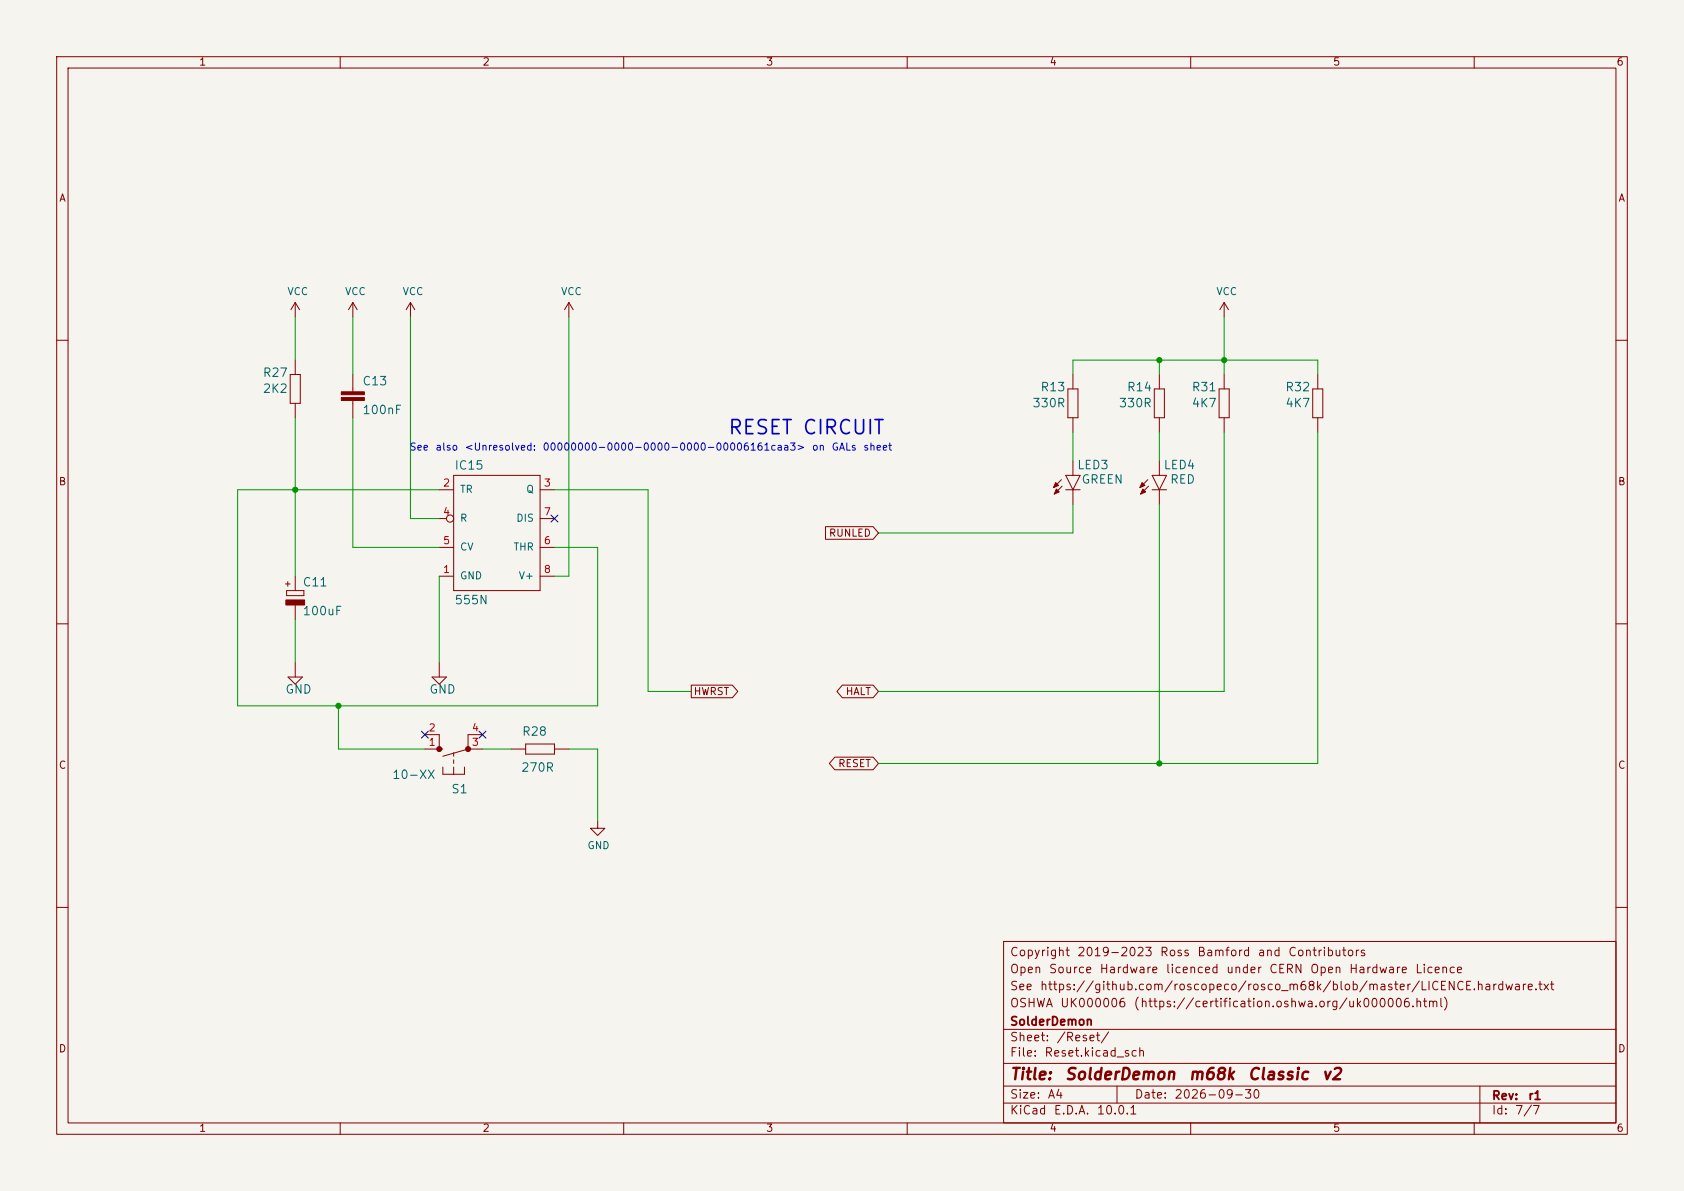
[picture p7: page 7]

Copyright 2019-2023 Ross Bamford and Contributors
Open Source Hardware licenced under CERN Open Hardware Licence
See https://github.com/roscopeco/rosco_m68k/blob/master/LICENCE.hardware.txt
OSHWA UK000006 (https://certification.oshwa.org/uk000006.html)
SolderDemon
Sheet: /Reset/
File: Reset.kicad_sch
Title: SolderDemon m68k Classic v2

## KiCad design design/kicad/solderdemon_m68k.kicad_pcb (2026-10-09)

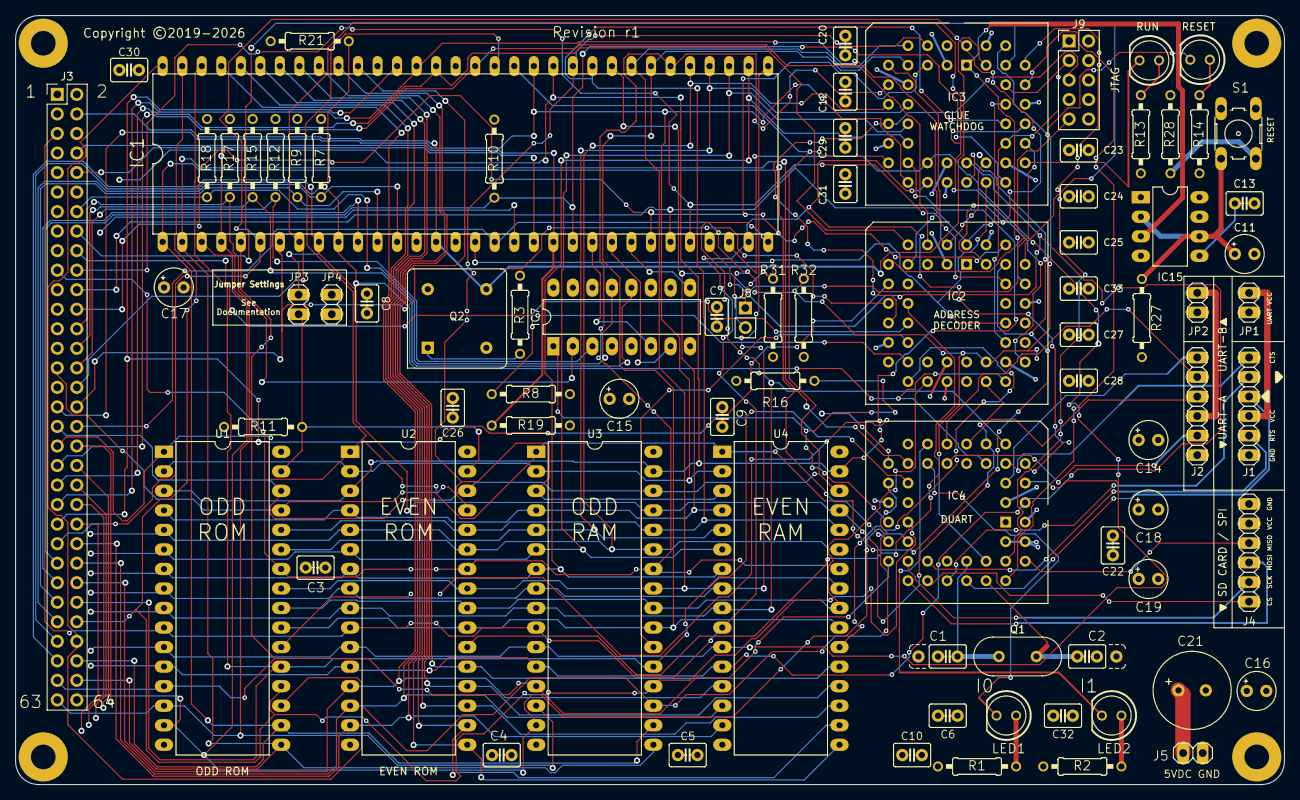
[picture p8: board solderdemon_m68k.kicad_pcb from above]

Board: 4 copper layers, 165.0 x 100.0 mm, 87 parts (1 on the bottom side), 111 nets.

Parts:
C1, C2: 7pF; C2.5_or_3.5-3
C3, C4, C5, C6, C7, C8, C9, C10, C12, C13, C20, C22, C23, C24, C25, C26, C27, C28, C29, C30, C31, C32, C33: 100nF; C2.5-3
C11, C14, C15, C16, C17, C18, C19: 100uF; E2,5-5
C21: 470uF; E3,5-10
H1, H2, H3, H4: MountingHole; MountingHole_3.2mm_M3_Pad
IC1: MC68010P10; DIL64
IC2, IC3: ATF1502AS-10JU44; PLCC-44_THT-Socket
IC4: XR68C681CJTR-F; PLCC-44_THT-Socket
IC7: 74LS148; DIP-16_W7.62mm_LongPads
IC15: 555N; DIP-8_W7.62mm_LongPads
J1: UART_A; 1X06
J2: UART_B; 1X06
J3: Conn_02x32_Odd_Even; PinHeader_2x32_P2.54mm_Vertical
J4: Conn_01x06; 1X06
J5: PWR; 1X02
J8: Conn_01x02_Male; PinHeader_1x02_P2.54mm_Vertical
J9: JTAG; PinHeader_2x05_P2.54mm_Vertical
JP1, JP2, JP3, JP4: Jumper; 1X02
LED1, LED3: GREEN; LED5MM
LED2, LED4: RED; LED5MM
LOGO1: SolderDemon_Logo
Q1: 3.6864MHz; Crystal_HC49-4H_Vertical
Q2: 5H8ET-10.000; Oscillator_DIP-8
R1, R2, R13, R14: 330R; 0207_10
R3, R7, R8, R9, R10, R12, R15, R16, R17, R18, R31, R32: 4K7; 0207_10
R11, R19: 10K; 0207_10
R21: 1K2; 0207_10
R27: 2K2; 0207_10
R28: 270R; 0207_10
S1: 10-XX; B3F-10XX
U1, U2: SST39SF040; DIP-32_W15.24mm_LongPads
U3, U4: AS6C4008-55PCN; DIP-32_W15.24mm_LongPads

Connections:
A1: IC1.29 (A1), IC3.25 (I/O/PD2), IC4.2 (A1), J3.1, U1.12 (A0), U2.12 (A0), U3.12 (A0), U4.12 (A0)
A2: IC1.30 (A2), IC3.21 (I/O), IC4.4 (A2), J3.3, U1.11 (A1), U2.11 (A1), U3.11 (A1), U4.11 (A1)
A3: IC1.31 (A3), IC3.20 (I/O), IC4.6 (A3), J3.5, U1.10 (A2), U2.10 (A2), U3.10 (A2), U4.10 (A2)
A4: IC1.32 (A4), IC4.7 (A4), J3.7, U1.9 (A3), U2.9 (A3), U3.9 (A3), U4.9 (A3)
A5: IC1.33 (A5), J3.9, U1.8 (A4), U2.8 (A4), U3.8 (A4), U4.8 (A4)
A6: IC1.34 (A6), IC3.16 (I/O), J3.11, U1.7 (A5), U2.7 (A5), U3.7 (A5), U4.7 (A5)
A7: IC1.35 (A7), IC3.14 (I/O), J3.13, U1.6 (A6), U2.6 (A6), U3.6 (A6), U4.6 (A6)
A8: IC1.36 (A8), IC3.12 (I/O), J3.15, U1.5 (A7), U2.5 (A7), U3.5 (A7), U4.5 (A7)
A9: IC1.37 (A9), IC3.11 (I/O/PD1), J3.17, U1.27 (A8), U2.27 (A8), U3.27 (A8), U4.27 (A8)
A10: IC1.38 (A10), IC3.9 (I/O), J3.19, U1.26 (A9), U2.26 (A9), U3.26 (A9), U4.26 (A9)
A11: IC1.39 (A11), IC3.8 (I/O), J3.21, U1.23 (A10), U2.23 (A10), U3.23 (A10), U4.23 (A10)
A12: IC1.40 (A12), IC3.6 (I/O), J3.23, U1.25 (A11), U2.25 (A11), U3.25 (A11), U4.25 (A11)
A13: IC1.41 (A13), IC3.31 (I/O), J3.25, U1.4 (A12), U2.4 (A12), U3.4 (A12), U4.4 (A12)
A14: IC1.42 (A14), IC3.34 (I/O), J3.27, U1.28 (A13), U2.28 (A13), U3.28 (A13), U4.28 (A13)
A15: IC1.43 (A15), IC3.28 (I/O), J3.29, U1.29 (A14), U2.29 (A14), U3.3 (A14), U4.3 (A14)
A16: IC1.44 (A16), IC3.19 (I/O), J3.31, U1.3 (A15), U2.3 (A15), U3.31 (A15), U4.31 (A15)
A17: IC1.45 (A17), IC3.18 (I/O), J3.33, U1.2 (A16), U2.2 (A16), U3.2 (A16), U4.2 (A16)
A18: IC1.46 (A18), IC3.17 (I/O), J3.35, U1.30 (A17), U2.30 (A17), U3.30 (A17), U4.30 (A17)
A19: IC1.47 (A19), IC2.41 (I/O/GCLK3), IC3.24 (I/O), J3.37, U1.1 (A18), U2.1 (A18), U3.1 (A18), U4.1 (A18)
A20: IC1.48 (A20), IC2.4 (I/O), J3.39
A21: IC1.50 (A21), IC2.6 (I/O), J3.41
A22: IC1.51 (A22), IC2.8 (I/O), J3.43
A23: IC1.52 (A23), IC2.9 (I/O), J3.45
AS: IC1.6 (AS), IC2.43 (I/GCLK1), IC3.44 (I/OE1/Vpp), J3.47
BERR: IC1.22 (BERR), IC3.4 (I/O), J3.49, R10.1
BG: IC1.11 (BG), J3.51
BGACK: IC1.12 (BGACK), J3.53, R9.1
BR: IC1.13 (BR), J3.55, R7.1
CLK: IC1.15 (CLK), IC3.43 (I/GCLK1), J3.4, Q2.5 (OUT)
CTSA: IC4.8 (IP0), J1.6
CTSB: IC4.5 (IP1), J2.6
D0: IC1.5 (D0), IC4.28 (D0), J3.61, U1.13 (D0), U3.13 (DQ0)
D1: IC1.4 (D1), IC4.18 (D1), J3.63, U1.14 (D1), U3.14 (DQ1)
D2: IC1.3 (D2), IC4.27 (D2), J3.64, U1.15 (D2), U3.15 (DQ2)
D3: IC1.2 (D3), IC4.19 (D3), J3.62, U1.17 (D3), U3.17 (DQ3)
D4: IC1.1 (D4), IC4.26 (D4), J3.60, U1.18 (D4), U3.18 (DQ4)
D5: IC1.64 (D5), IC4.20 (D5), J3.58, U1.19 (D5), U3.19 (DQ5)
D6: IC1.63 (D6), IC4.25 (D6), J3.56, U1.20 (D6), U3.20 (DQ6)
D7: IC1.62 (D7), IC4.21 (D7), J3.54, U1.21 (D7), U3.21 (DQ7)
D8: IC1.61 (D8), J3.52, U2.13 (D0), U4.13 (DQ0)
D9: IC1.60 (D9), J3.50, U2.14 (D1), U4.14 (DQ1)
D10: IC1.59 (D10), J3.48, U2.15 (D2), U4.15 (DQ2)
D11: IC1.58 (D11), J3.46, U2.17 (D3), U4.17 (DQ3)
D12: IC1.57 (D12), J3.44, U2.18 (D4), U4.18 (DQ4)
D13: IC1.56 (D13), J3.42, U2.19 (D5), U4.19 (DQ5)
D14: IC1.55 (D14), J3.40, U2.20 (D6), U4.20 (DQ6)
D15: IC1.54 (D15), J3.38, U2.21 (D7), U4.21 (DQ7)
DTACK: IC1.10 (DTACK), IC2.28 (I/O), IC4.10 (*DTALK), J3.57, R21.2
DUAIACK: IC3.39 (I/O), IC4.41 (*IACK)
DUAIRQ: IC4.24 (INTR), IC7.1 (I4), R16.2
DUASEL: IC3.37 (I/O), IC4.39 (CS)
E: IC1.20 (E), J3.10
EVENRAMSEL: IC2.18 (I/O), U4.22 (CE)
EVENROMSEL: IC2.12 (I/O), U2.22 (CE)
EXPSEL: IC2.19 (I/O), J3.18
FC0: IC1.28 (FC0), IC2.2 (I/OE2/GCLK2), IC3.27 (I/O), J3.20
FC1: IC1.27 (FC1), IC2.44 (I/OE1/Vpp), IC3.36 (I/O), J3.22
FC2: IC1.26 (FC2), IC2.40 (I/O), IC3.5 (I/O), J3.24
GND: C1.1, C2.1, C3.2, C4.2, C5.2, C6.2, C7.2, C8.2, C9.2, C10.2, C11.-, C12.2, C14.-, C15.-, C16.-, C17.-, C18.-, C19.-, C20.2, C21.-, C22.2, C23.2, C24.2, C25.2, C26.2, C27.2, C28.1, C29.1, C30.1, C31.2, C32.2, C33.2, H1.1, H2.1, H3.1, H4.1, IC1.16 (GND@1), IC1.53 (GND@2), IC2.10 (GND), IC2.22 (GND), IC2.30 (GND), IC2.42 (GND), IC3.10 (GND), IC3.22 (GND), IC3.30 (GND), IC3.42 (GND), IC4.3 (IP3), IC4.22 (GND), IC4.42 (IP5), IC4.43 (IP4), IC7.5 (EI), IC7.8 (GND), IC7.10 (IO), IC15.1 (GND), J1.1, J2.1, J3.6, J4.6, J5.2, J9.2, J9.10, JP4.2 (B), Q2.4 (GND), R28.1, U1.16 (GND), U2.16 (GND), U3.16 (VSS), U4.16 (VSS)
HALT: IC1.17 (HALT), IC2.34 (I/O), IC3.26 (I/O), J8.1, R31.1
HWRST: IC2.37 (I/O), IC3.1 (I/GCLR), IC15.3 (Q)
IOSEL: IC2.39 (I/O), IC3.41 (I/O/GCLK3), J3.16
IPL0: IC1.25 (IPL0), IC7.9 (S0)
IPL1: IC1.24 (IPL1), IC7.7 (S1)
IPL2: IC1.23 (IPL2), IC7.6 (S2)
IRQ2: IC7.12 (I2), J3.28, R15.2
IRQ3: IC7.13 (I3), J3.14, R18.2
IRQ5: IC7.2 (I5), J3.26, R17.2
IRQ6: IC7.3 (I6), J3.30, R12.2
JTAG_CHAIN: IC2.38 (I/O/TDO), IC3.7 (I/O/TDI)
JTAG_TCK: IC2.32 (I/O/TCK), IC3.32 (I/O/TCK), J9.1
JTAG_TDI: IC2.7 (I/O/TDI), J9.9
JTAG_TDO: IC3.38 (I/O/TDO), J9.3
JTAG_TMS: IC2.13 (I/O/TMS), IC3.13 (I/O/TMS), J9.5
LDS: IC1.8 (LDS), IC2.29 (I/O), IC3.33 (I/O), J3.32
LGEXP: IC2.14 (I/O), JP4.1 (A), R8.2
unnamed: IC4.15 (OP3), LED2.K (C)
unnamed: IC4.16 (OP5), LED1.K (C)
unnamed: C1.2, IC4.36 (X1/CLK), Q1.1
unnamed: C2.2, IC4.37 (X2), Q1.2
unnamed: C13.2, IC15.5 (CV)
unnamed: C11.+, IC15.2 (TR), IC15.6 (THR), R27.1, S1.1 (S)
unnamed: LED1.A, R1.1
unnamed: LED2.A, R2.1
unnamed: LED3.A, R13.1
unnamed: LED4.A, R14.1
unnamed: Q2.1 (EN), R3.2
unnamed: R28.2, S1.3
ODDRAMSEL: IC2.16 (I/O), U3.22 (CE)
ODDROMSEL: IC2.17 (I/O), U1.22 (CE)
RESET: IC1.18 (RESET), IC2.27 (I/O), IC3.40 (I/O), IC4.38 (*RESET), J3.36, J8.2, LED4.K (C), R32.1
ROM_RW: JP3.2 (B), R11.2, U1.31 (PGM), U2.31 (PGM)
RTSA: IC4.32 (OP0), J1.2
RTSB: IC4.14 (OP1), J2.2
RUNLED: IC3.29 (I/O), LED3.K (C)
RW: IC1.9 (R/W), IC2.26 (I/O), IC4.9 (*R/*W), J3.59, JP3.1 (A), U3.29 (WE), U4.29 (WE)
RXDA: IC4.35 (RXDA), J1.4
RXDB: IC4.11 (RXDB), J2.4
SPICLK: IC4.30 (OP4), J4.2
SPICS: IC4.31 (OP2), J4.1
SPIMISO: IC4.40 (IP2), J4.4
SPIMOSI: IC4.29 (OP6), J4.3
TXDA: IC4.33 (TXDA), J1.5
TXDB: IC4.13 (TXDB), J2.5
UDS: IC1.7 (UDS), IC2.11 (I/O/PD1), J3.34
VCC: C3.1, C4.1, C5.1, C6.1, C7.1, C8.1, C9.1, C10.1, C12.1, C13.1, C14.+, C15.+, C16.+, C17.+, C18.+, C19.+, C20.1, C21.+, C22.1, C23.1, C24.1, C25.1, C26.1, C27.1, C28.2, C29.2, C30.2, C31.1, C32.1, C33.1, IC1.14 (VCC@1), IC1.49 (VCC@2), IC2.3 (VCC), IC2.15 (VCC), IC2.23 (VCC), IC2.35 (VCC), IC3.3 (VCC), IC3.15 (VCC), IC3.23 (VCC), IC3.35 (VCC), IC4.44 (VCC), IC7.4 (I7), IC7.11 (I1), IC7.16 (VCC), IC15.4 (R), IC15.8 (V+), J3.2, J4.5, J5.1, J9.4, JP1.2 (B), JP2.2 (B), Q2.8 (Vcc), R1.2, R2.2, R3.1, R7.2, R8.1, R9.2, R10.2, R11.1, R12.1, R13.2, R14.2, R15.1, R16.1, R17.1, R18.1, R19.1, R21.1, R27.2, R31.2, R32.2, U1.32 (VCC), U2.32 (VCC), U3.32 (VCC), U4.32 (VCC)
VCCUA: J1.3, JP1.1 (A)
VCCUB: J2.3, JP2.1 (A)
VMA: IC1.19 (VMA), J3.12
VPA: IC1.21 (VPA), J3.8, R19.2
WR: IC2.20 (I/O), U1.24 (OE), U2.24 (OE), U3.24 (OE), U4.24 (OE)

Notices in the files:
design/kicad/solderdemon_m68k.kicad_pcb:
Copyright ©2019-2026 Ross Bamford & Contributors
